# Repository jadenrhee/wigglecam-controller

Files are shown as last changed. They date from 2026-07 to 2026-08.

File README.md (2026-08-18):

# WiggleCam Camera Controller

The RP2040 board that handles timing-critical and analog work for a
[4-lens camera](https://github.com/jadenrhee/wigglecam). The Raspberry
Pi runs capture and image processing, but Linux is not a real-time OS
and the Pi can't drive the flash directly.

This board runs the LED flash at constant current, with the limits set
in the circuit rather than only in firmware. It also debounces the
shutter, decodes the EC11 encoder, and monitors battery voltage and
current through an INA219. On a trigger it pulses the Pi the instant the
LEDs reach full current.

The Pi drives it over I2C at 0x17, and the capture pulse returns on its
own GPIO line. The 2x6 header maps 1:1 onto Pi 5 GPIO pins 1 to 12.

Not fabricated yet, so everything here comes from the design files.

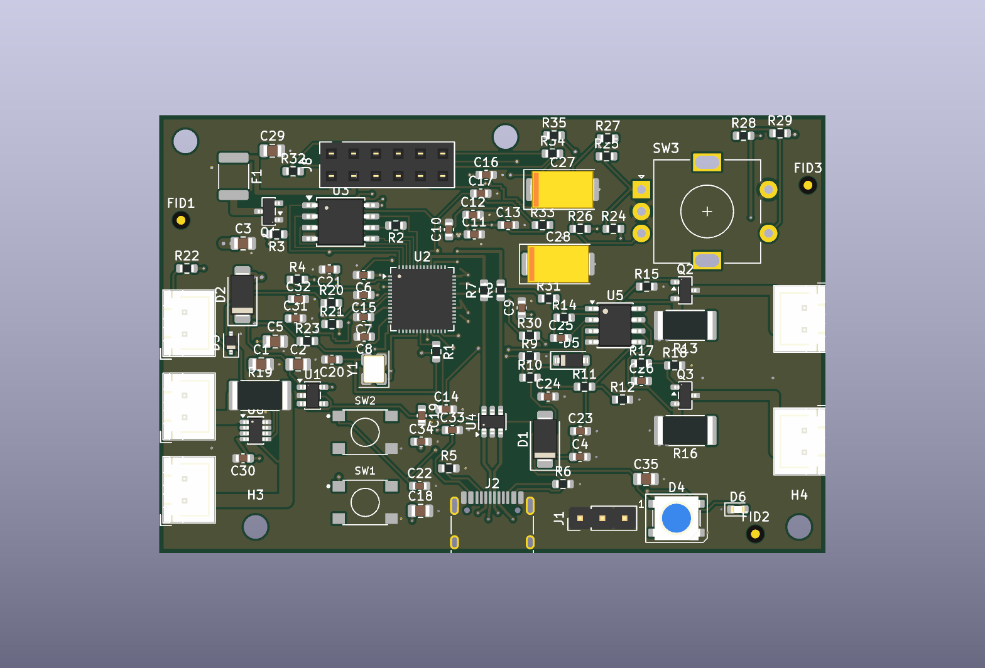
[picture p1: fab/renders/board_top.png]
Board, top

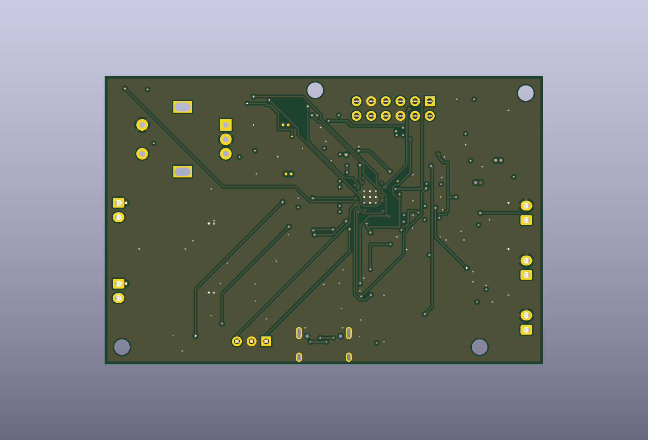
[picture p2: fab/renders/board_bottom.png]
Board, bottom


Signal routing, front copper red and back copper blue, planes hidden:

Routing view

| | |
|---|---|
| Board | 76 x 50 mm, 4 layers |
| Schematic | ERC clean, 0 errors and 0 warnings |
| Layout | DRC clean, 0 violations and 0 unconnected, against JLCPCB's published 4-layer rules |
| Verification | 24 checks measured off the finished layout, no failures. [Report](docs/verification-report.md) |
| Firmware | builds clean under the Pico SDK |
| Fab outputs | Gerbers, drill, BOM, and placement files in [fab/](fab/); the ready-to-upload set is [fab/jlc/](fab/jlc/) |

## Repo layout

| Path | Contents |
|---|---|
| [hardware/skidl/](hardware/skidl/) | schematic as code, the source of record |
| [hardware/kicad/](hardware/kicad/) | the board file and custom footprints |
| [hardware/partlist.md](hardware/partlist.md) | every part, the reasoning behind it, and where to order it |
| [fab/](fab/) | Gerbers, Excellon drill, `bom.csv`, `cpl.csv`, renders |
| [firmware/](firmware/) | C firmware: I2C register file, flash safety logic, INA219, EC11, WS2812 |
| [enclosure/](enclosure/) | 3D-printable pod holding the screen, this board, and the Pi 5 |
| [docs/](docs/) | [verification report](docs/verification-report.md), [design rationale](docs/design-rationale.md), and the [Pi protocol](docs/protocol.md) |

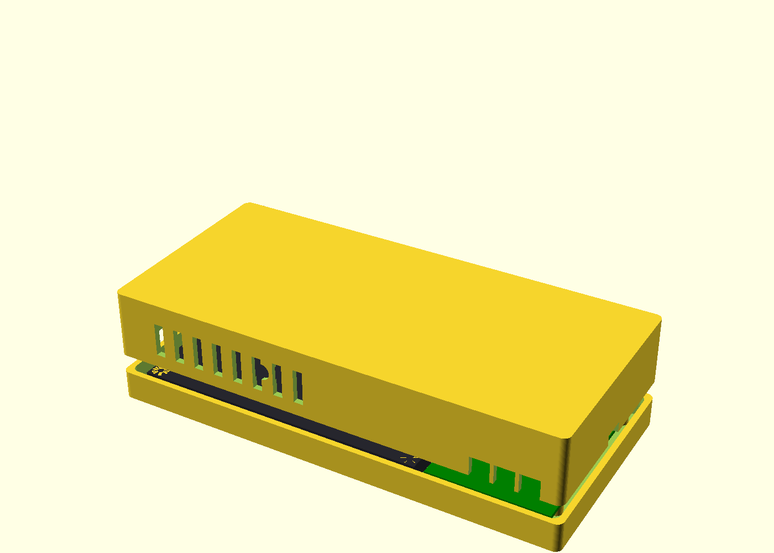
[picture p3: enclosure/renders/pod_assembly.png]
pod


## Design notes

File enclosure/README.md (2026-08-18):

# Control pod enclosure

Two-shell 3D-printable case (≈191 × 89 × 40 mm) housing the camera's
brain: the 4.3" DSI touchscreen behind the left of the face, this
repo's controller PCB behind the right-hand control strip (components
facing out so the encoder knob, status-LED light pipe and
BOOTSEL/RUN poke-holes come through the face; USB-C exits the right wall), and a
Raspberry Pi 5 flat on the rear floor.

assembly
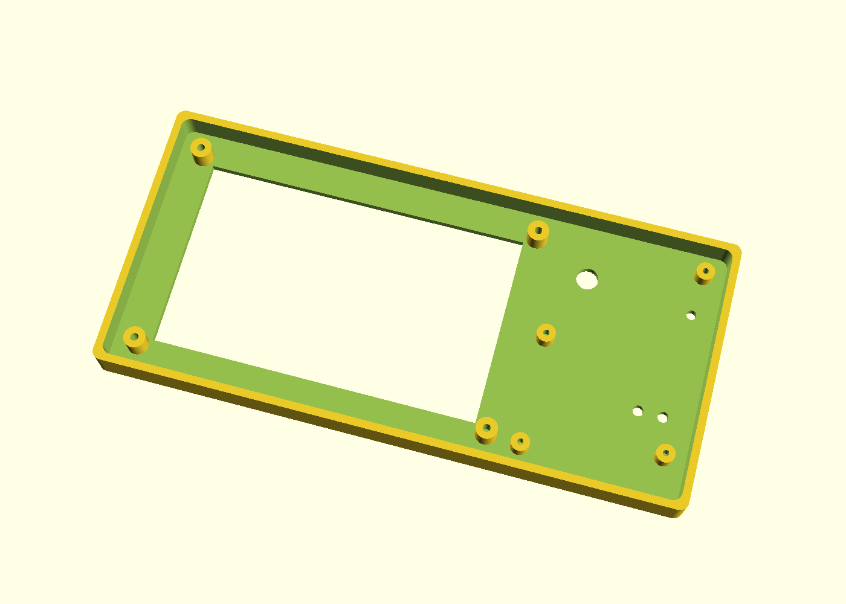
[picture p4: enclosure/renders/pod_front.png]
front shell

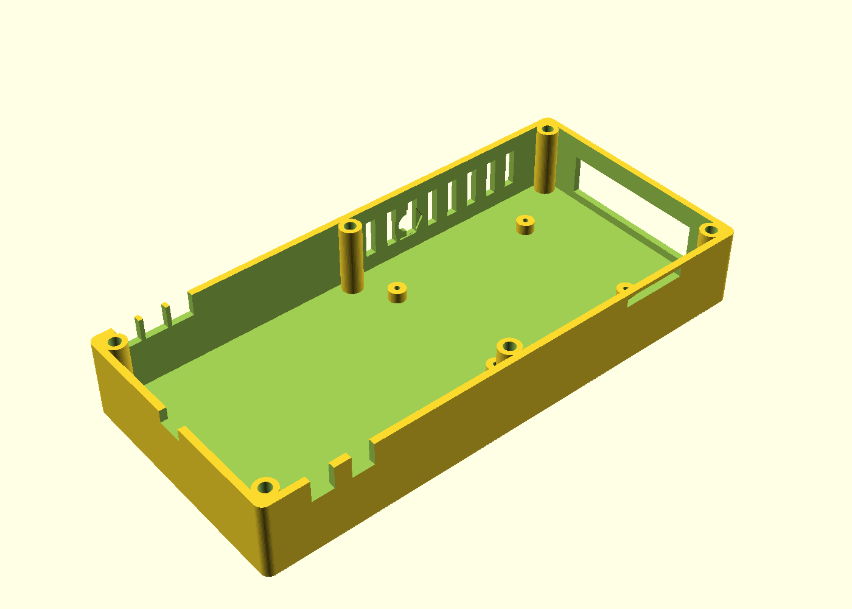
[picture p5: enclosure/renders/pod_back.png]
back shell


**The PCB cannot mis-mate:** every board-related feature (mounting
bosses, encoder hole, LED pipe, button holes, USB-C window, cable
slots) is generated from the routed `.kicad_pcb` via
the routed board → [board_dims.scad](board_dims.scad).
If the layout ever changes, re-run the extractor and re-export.

## Ordering prints (no printer needed)

Upload `stl/pod_front.stl` and `stl/pod_back.stl` to any of:

- **[JLC3DP](https://jlc3dp.com)** is the cheapest. Pick **SLS Nylon
  (PA12)** for a clean, strong result (~$15-25 for the pair), or resin
  if you want smoother faces.
- **[Craftcloud](https://craftcloud3d.com)** compares prices across
  many services.
- A **library / school makerspace** FDM printer also works: PETG,
  0.2 mm layers, 4 walls, 25 % infill; print both shells face-down
  (flat side on the bed), no supports needed except the side windows
  (bridging distance is small enough for a tuned printer).

**Before ordering**, measure your delivered screen with calipers and
update `scr_*` in [control_pod.scad](control_pod.scad), the
Waveshare 4.3" module outline/hole values here are typical but marked
`TODO(measure)` because vendor revisions drift.

## Assembly hardware

| Item | Qty | Use |
|---|-----|-----|
| M3 heat-set inserts + M3×12 screws | 6 | join the shells |
| M2×6 self-tapping screws | 4 | controller PCB onto its bosses |
| M2.5×6 self-tapping screws | 4 | Pi 5 onto the floor bosses |
| M3×6 self-tapping screws | 4 | screen module |
| 3 mm acrylic rod, ~6 mm piece | 1 | WS2812 light pipe (press-fit, dab of CA glue) |
| 12-way 2.54 mm ribbon, 2×6 IDC both ends, ~80 mm | 1 | controller J8 → Pi GPIO pins 1-12 |
| Knob for 6 mm D-shaft | 1 | encoder |
| The encoder's own M7 nut + washer | - | clamps the PCB assembly to the face |

## Assembly order

1. Heat-set the six M3 inserts into the back-shell towers.
2. Press the light pipe into the face from inside; trim flush.
3. Screw the controller PCB (components toward the face) onto its
   four bosses; add the encoder washer + nut on the outside; fit the
   knob.
4. Screw the screen into its pocket; route its DSI cable.
5. Screw the Pi onto the floor bosses (active cooler up); connect
   DSI to the screen, the 12-way ribbon to the controller, and the
   camera ribbon through the top slit.
6. Route the JST harnesses (LED ×2 top, VBAT ×2 + shutter bottom)
   through their slots before closing.
7. Close the shells, six M3 screws. The 1/4-20 nut epoxies into the
   bottom pocket for tripod use.

## Regenerating

```bash
# dimensions from the PCB (KiCad's bundled python):
KIPY private/scripts/08_enclosure_dims.py
# STLs + renders:
OpenSCAD -o enclosure/stl/pod_front.stl -D 'PART="front"' enclosure/control_pod.scad
OpenSCAD -o enclosure/stl/pod_back.stl  -D 'PART="back"'  enclosure/control_pod.scad
```

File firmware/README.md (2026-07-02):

# Camera Controller firmware

RP2040 firmware (Pico SDK, C). See [../docs/protocol.md](../docs/protocol.md)
for the I2C register map the Pi talks to.

## Build

```bash
export PICO_SDK_PATH=~/pico-sdk
# any arm-none-eabi toolchain with newlib; xpack works well:
export PICO_TOOLCHAIN_PATH=~/tools/xpack-arm-none-eabi-gcc-14.2.1-1.1/bin
cmake -B build -S . -DCMAKE_BUILD_TYPE=Release
make -C build -j4
```

Flash: hold BOOTSEL while plugging USB-C, then copy
`build/camctrl.uf2` to the RPI-RP2 drive.

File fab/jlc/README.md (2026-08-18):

# JLCPCB upload set

Three files, in this order.

| Step | File |
|---|---|
| PCB | `../wigglecam_gerbers.zip` (upload as-is, do not unzip) |
| BOM | `bom-smt.csv` |
| Placement | `cpl-smt.csv` |

PCB settings: **4 layers**, 76 x 50 mm, **1.6 mm** thickness, 1 oz outer
copper. Assembly: **top side only** (all 90 placements are top side).

## What these files are

`bom-smt.csv` / `cpl-smt.csv` hold the 90 surface-mount placements and
nothing else. The eight through-hole parts are split out into
`bom-handsolder.csv` so the upload has no rows JLC has to reject.

`../bom.csv` and `../cpl.csv` remain the complete set for the whole
board, all 98 placements.

## Hand-soldered separately

J1, J3, J4, J5, J6, J7, J8, SW3. Buy these yourself; they are not in
the JLC upload. All are 2.54 mm headers, JST-XH, or the EC11 encoder,
so none of them is difficult.

## Parts to confirm in the picker

Stock moves daily, so the last step happens in JLC's BOM tool, not
here. Note that JLC's assembly inventory is a different pool from
LCSC's retail stock: a part can be buyable at LCSC and still show a
shortfall in the BOM tool. When that happens the cheapest fix is
usually to deselect it and hand-solder one bought from LCSC.

Expect to resolve these:

- **R12** is C22765 (1.2 k 0603 1 %, JLC basic). It sets the flash
  reference: 1.2 k settles at 0.508 V, giving 1.015 A per LED branch.
  **Do not substitute 1 k** (0.434 V, 0.87 A) or 1.1 k (0.471 V,
  0.94 A).
- **D4 (WS2812B)** is often flagged "Standard Only" on Economic
  assembly. Deselect and hand-solder it if so; it is a 4-pad 5050.
- Anything showing an inventory shortfall: deselect it and hand-solder,
  or pick an equivalent. Nothing here is exotic except the parts
  called out in `../../hardware/partlist.md`.

The one part that cannot simply be dropped is **U1 (AP2112K-3.3,
SOT-23-5)**. It is the 3.3 V rail for the RP2040, flash, INA219 and
WS2812, so the board does nothing without it. If C51118 is short, use
**ME6211C33M5G-N (C82942)**: same SOT-23-5 pinout, 500 mA instead of
600 mA, which still leaves better than 2x margin on this board's
221 mA worst case. Any other substitute needs its pinout checked
against 1 VIN, 2 GND, 3 EN, 4 NC, 5 VOUT first, because plenty of
SOT-23-5 regulators number those differently.

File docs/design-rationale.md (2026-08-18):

# Design rationale, block by block

Datasheets:

- [RP2040](https://datasheets.raspberrypi.com/rp2040/rp2040-datasheet.pdf)
- [Hardware design with RP2040](https://datasheets.raspberrypi.com/rp2040/hardware-design-with-rp2040.pdf)
- [W25Q128JV](https://www.winbond.com/resource-files/w25q128jv%20revf%2003272018%20plus.pdf)
- [AP2112](https://www.diodes.com/assets/Datasheets/AP2112.pdf)
- [USBLC6-2](https://www.st.com/resource/en/datasheet/usblc6-2.pdf)
- [INA219](https://www.ti.com/lit/ds/symlink/ina219.pdf)
- [AO3400A](http://aosmd.com/pdfs/datasheet/AO3400A.pdf) /
  [AO3401A](http://aosmd.com/pdfs/datasheet/AO3401A.pdf)
- [LM358](https://www.ti.com/lit/ds/symlink/lm358.pdf)

## MCU core
Bare RP2040 with the support circuit taken directly from the official
guide's Minimal Design Example: 12 MHz ABM8-272-T3 (CL = 10 pF → two
15 pF C0G load caps, 1 kΩ series on XOUT limits drive), W25Q128JVSIQ
QSPI flash 9 mm away with a 27 Ω series option in SCLK, 100 nF at
every IOVDD/USB_VDD/ADC_AVDD, two 100 nF + 1 µF on the internal
1.1 V regulator, BOOTSEL (QSPI_SS to GND) and RUN buttons wired on
diagonal tact-switch pads so either internal pairing convention works.

## Power input
Pi 5 V enters through a 3 A PTC and an AO3401A P-FET oriented
drain-to-input (body diode conducts at first power, channel then
enhances; reversed input blocks). The post-FET node **is** the flash
rail (VLED) and feeds the logic rail through one of two SS34 OR-diodes.
The other diode comes from USB VBUS, so a bench USB port can never be
asked for the 2 A flash pulse. AP2112K-3.3 (600 mA) supplies logic
with 3× margin.

## Flash driver
Two independent op-amp constant-current sinks (½ LM358 + AO3400A +
0.5 Ω sense each): I = VREF / 0.5 Ω, VREF = 0-0.5 V from an RC-filtered
RP2040 PWM through a 5.6 k/1.2 k divider. The RC filter's 1 k sits in
series with the top leg, so the bottom leg is 1.2 k, not 1 k,
and full scale settles at 3.3 × 1.2/(1 + 5.6 + 1.2) ≈ 0.51 V
(1.015 A/branch). A 100 kΩ pulldown holds the reference at zero through reset, so the
flash cannot fire until firmware commands it. An AL8860 buck was
rejected because from a 5 V rail it cannot drive a series LED string
(Vf 6-9 V), which would mean one
driver+inductor per LED, all JLC extended parts. Worst-case sink
dissipation ≈1.4 W for ≤150 ms (firmware-capped, plus 800 ms
cooldown), within the SOT-23 single-pulse transient envelope with
margin (AO3400A Zth curve). Reservoir: 2× 470 µF low-ESR polymer on
the VLED island.

## Battery monitor
INA219 high-side on a JST-in/JST-out pass-through with a 10 mΩ 2 W
shunt (5 A → 50 mV, inside the ±320 mV PGA range). It lives on a
separate internal I2C bus (RP2040 master) so its traffic never
touches the Pi-facing bus; firmware caches readings. The layout's
sense taps are not Kelvin. They join the 1.5 mm battery trace a few
mm from the shunt pads, so roughly 3 mΩ of trace copper sits inside
the sense loop and uncorrected readings run ~30 % high. Firmware
carries an effective-shunt-resistance trim constant
(`SHUNT_EFF_MOHM`, firmware/src/ina219.c) to calibrate out at
bring-up.

## Controls & status
Shutter and encoder lines get 10 k pullups + 1 k series + 100 nF RC
(hardware debounce first stage). The shutter leaves the enclosure, so
it also gets a PESD5V0S1BA TVS at the connector. WS2812B runs its
VDD through a 1N4148W drop (~4.3 V) so 3.3 V logic meets the 0.7·VDD
input threshold. One green LED on GPIO25 keeps the Pico debugging
convention.

## Pi interface
2×6 socket matching Pi 5 GPIO pins 1-12 exactly: I2C (slave 0x17),
a UART pair (wired, unused by the current firmware), camera-sync out
(→ Pi GPIO17), event/ATTN line (→ Pi GPIO18),
5 V in, grounds. 330 Ω series resistors on the push-pull lines as
contention insurance; the I2C lines connect directly because the Pi 5
carries 1.8 kΩ hardware pullups.

## Board & layout strategy
76×50 mm 4-layer (JLC04161H-7628): L1 signal, L2 solid GND, L3 3V3
plane + a tightly-drawn VLED island (west entry lobe → 1.6 mm conduit
finger → reservoir pocket → right strip to the LED connectors), L4
signal. The sensitive geometry (QSPI nested-lane fanout, crystal, USB
pair with its mirror-pad B.Cu jumpers, power entry, battery path, LED
returns, plane fanouts) is laid out with explicit crossing-free
geometry, and the inner layers carry no signal routing at all, so the
planes stay whole under the fast nets. Everything gates through
`kicad-cli drc --refill-zones` at JLCPCB capability limits. The
final board reports **0 violations, 0 unconnected** (see
docs/verification-report.md).

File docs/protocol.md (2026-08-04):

# Pi ⇄ Camera Controller protocol

Bus: I2C, RP2040 as slave at **0x17** on the Pi's I2C1 (GPIO2/3,
400 kHz; the Pi 5's onboard 1.8 kΩ pullups serve the bus). Register
semantics follow SMBus conventions: write `[reg]` then data bytes
(auto-increment), or write `[reg]` + repeated-start read.

A second signal, **ATTN** (RP2040 GPIO7 → Pi GPIO18), goes high while
any button/encoder event is latched, so the Pi can poll cheaply or
take a GPIO interrupt instead of polling I2C.

The capture-sync line (**RP2040 GPIO6 → Pi GPIO17**) pulses high when
a trigger fires; the Pi's capture loop waits on this edge so the
exposure lands inside the flash window.

## Register map

| Addr | Name | R/W | Meaning |
|---|---|-----|---|
| 0x00 | WHO_AM_I | R | always 0xCA |
| 0x01 | STATUS | R | bit0 trigger engine busy (flash or sync pulse in progress), bit1 event pending |
| 0x02 | TRIGGER | W | 1 = sync pulse only; 2 = flash + sync (flash reaches steady current ~5 ms before the sync edge; degrades to sync only if FLASH_PCT is 0 **or during the 800 ms post-flash cooldown**, but the sync edge always arrives); any other value is ignored. Writes while STATUS bit0 is set are dropped, so poll it before triggering. Back-to-back writes coalesce (last one wins). |
| 0x03 | FLASH_MS | RW | flash duration, clamped 1-150 ms (default 30) |
| 0x04 | FLASH_PCT | RW | flash current 0-100 % of 1.00 A/branch (default 80) |
| 0x05 | FIRE_FLASH | W | flash pulse without sync (e.g. focus assist) |
| 0x06-07 | VBAT | R | battery voltage, mV, little-endian u16; read low byte first, which snapshots the high byte so the pair is tear-free. A high byte read without its low byte returns the previous snapshot, not the live value |
| 0x08-09 | IBAT | R | battery current, mA, little-endian i16; same low-byte-first snapshot rule |
| 0x0A | ENC_DELTA | R | signed whole-detent count since last read (clears; a sub-detent remainder carries into the next read) |
| 0x0B | BUTTONS | R | bit0 shutter, bit1 encoder push (clears; ATTN drops once no events remain) |
| 0x0C-0E | LED R/G/B | RW | status LED color staging |
| 0x0F | LED_APPLY | W | latch staged RGB to the WS2812B |

Writes to read-only registers are dropped.

## Safety behavior (firmware-enforced, mirrors the hardware)

- Total LED-on time hard-capped at 150 ms; the ~5 ms pre-sync settle
  counts against the cap. 800 ms cooldown between pulses (SOT-23 sink
  transient thermal budget).
- The PWM pin idles low and the board's 100 kΩ pulldown holds the
  current-sink reference at 0 V through reset/boot, so the flash
  cannot fire until firmware explicitly commands it.
- 500 ms hardware watchdog; a hung firmware resets to flash-off.

## Example (Pi side, python3-smbus2)

```python
from smbus2 import SMBus
bus = SMBus(1)
assert bus.read_byte_data(0x17, 0x00) == 0xCA
bus.write_byte_data(0x17, 0x03, 40)   # 40 ms flash
bus.write_byte_data(0x17, 0x04, 90)   # 90 % current
bus.write_byte_data(0x17, 0x02, 2)    # flash + sync capture
mv = bus.read_word_data(0x17, 0x06)   # battery mV
```

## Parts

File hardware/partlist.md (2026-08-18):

# Part list (verified against LCSC stock, 2026-07-02)

Every named part below was individually confirmed present and in stock
at LCSC on the date above, except where a row says "confirm at order". Prices are the LCSC
from-price at qty 1; re-check stock at order time, it moves.
"JLC class" (basic vs extended, affects assembly setup fees) should be
confirmed in the JLCPCB BOM tool at order time; known classes noted.

**2026-07-03 update:** refdes corrected to match the routed board
(`fab/bom.csv` is the authoritative refdes source), generic-passive
picks added (each number verified against its LCSC product page for
value + package), and the 470 µF reservoir got its concrete pick.

## MCU core

| Ref | Part | Package | LCSC | ~$ | Notes |
|-----|---|---|---|----|---|
| U2 | [RP2040](https://www.lcsc.com/product-detail/C2040.html) | QFN-56 7×7 | **C2040** | 0.70 | in stock; support circuit per the official *Hardware design with RP2040* guide |
| U3 | [W25Q128JVSIQ](https://www.lcsc.com/product-detail/NOR-FLASH_Winbond-Elec-W25Q128JVSIQ_C97521.html) 16 MB QSPI | SOIC-8 | **C97521** | 0.47 | in stock; the flash used on the Pico |
| Y1 | [ABM8-272-T3](https://www.lcsc.com/product-detail/C20625731.html) 12 MHz, CL = 10 pF | 3225 | **C20625731** | 0.15 | in stock; the exact crystal from the RP2040 guide's minimal example → 15 pF load caps + 1 kΩ series R on XOUT, straight from the guide |
| SW1, SW2 | [TS-1187A-B-A-B](https://www.lcsc.com/product-detail/C318884.html) BOOTSEL + RUN | SMD 5.1 mm | **C318884** | 0.01 | in stock, JLC **basic**. Known deviation: no 1 kΩ in series with the BOOTSEL button (reference design has one) |
| J1 | SWD header 1×3, 2.54 mm | THT | generic | - | hand-solder; any vendor |

## Power

| Ref | Part | Package | LCSC | ~$ | Notes |
|-----|---|---|---|----|---|
| U1 | [AP2112K-3.3TRG1](https://www.lcsc.com/product-detail/C51118.html) 600 mA LDO | SOT-23-5 | **C51118** | 0.09 | **Alternate if short: [ME6211C33M5G-N](https://www.lcsc.com/product-detail/C82942.html) (C82942), 278 k in stock.** Same SOT-23-5 pinout (1 VIN, 2 GND/VSS, 3 EN/CE, 4 NC, 5 VOUT), 500 mA instead of 600 mA. The 3V3 rail draws 221 mA worst case (RP2040 200 mA peak + INA219 + WS2812), so 44 % of rating, and dropout at 200 mA is 260 mV against ~1.0 V of headroom from VSYS. Same 1 µF/10 µF caps. |
| Q1 | [AO3401A](https://www.lcsc.com/product-detail/C15127.html) P-ch, reverse-polarity protection | SOT-23 | **C15127** | 0.05 | in stock, JLC **basic**; polarity-critical in the JLC preview |
| D1, D2 | [SS34](https://www.lcsc.com/product-detail/C8678.html) 3 A Schottky, VBUS/VLED diode-OR | SMA | **C8678** | 0.03 | cathode bands polarity-critical in the JLC preview |
| F1 | [BSMD1812-300-16V](https://www.lcsc.com/product-detail/C883162.html) PTC, 3 A hold | 1812 | **C883162** | - | Pi-5V input fuse |

## USB-C

| Ref | Part | Package | LCSC | ~$ | Notes |
|-----|---|---|---|----|---|
| J2 | [TYPE-C-31-M-12](https://www.lcsc.com/product-detail/USB-Type-C_Korean-Hroparts-Elec-TYPE-C-31-M-12_C165948.html) 16-pin | SMD+THT shell | **C165948** | 0.10 | in stock; the de-facto hobby USB-C jack, hand-solderable |
| U4 | [USBLC6-2SC6](https://www.lcsc.com/product-detail/C7519.html) ESD array | SOT-23-6 | **C7519** | 0.08 | in stock; in D± path before the MCU |
| R7, R8 | 27 Ω 1 % D± series | 0603 | **C25190** | - | guide-nominal 27 Ω (Pico's 27.4 Ω is the E96 neighbour, equivalent at USB-FS); JLC **basic** |

## Flash driver (constant-current, discrete; see decision note below)

| Ref | Part | Package | LCSC | ~$ | Notes |
|-----|---|---|---|----|---|
| U5 | [LM358DR2G](https://www.lcsc.com/product-detail/General-Purpose-Amplifiers_ON-Semiconductor-LM358DR2G_C7950.html) dual op-amp | SOIC-8 | **C7950** | 0.03 | in stock, JLC **basic**; one half per LED branch |
| Q2, Q3 | [AO3400A](https://www.lcsc.com/product-detail/MOSFET_AOS_AO3400A_AO3400A_C20917.html) N-ch sink FETs | SOT-23 | **C20917** | 0.05 | in stock, JLC **basic**; 150 ms pulse-thermal disposition in the verification report |
| R13, R16 | [RTT25R500FTE](https://www.lcsc.com/product-detail/C105149.html) 0.5 Ω 1 % 1 W sense | 2512 | **C105149** | 0.02 | 1 A per branch → 0.5 V sense; 0.5 W only during the ≤150 ms pulse |
| C27, C28 | [6TPE470MI](https://www.lcsc.com/product-detail/Tantalum-Capacitors_PANASONIC_C402828.html) 470 µF 6.3 V 18 mΩ POSCAP | EIA-7343 | **C402828** | - | the low-ESR polymer reservoir the sizing math assumes; 6.3 V on a ~4.9 V rail ≈ 78 %, inside polymer derating practice |
| J3, J4 | [B2B-XH-A(LF)(SN)](https://www.lcsc.com/product-detail/C158012.html) JST-XH 2-pin, LED branches out | THT | **C158012** | - | genuine JST; LEDs (2× XP-G3 stars) live off-board at the flash window; hand-solder |

**Why a discrete sink instead of the AL8860:** the AL8860 is a *buck*
driver, so from a 5 V rail it cannot drive a 2-3-LED series string
(6-9 V); you'd need one AL8860 + inductor per LED, all JLC extended
parts. The discrete sink (LM358 + AO3400A + sense R, all JLC basic)
drives two parallel 1 A branches from 5 V at lower cost, with true
constant-current regulation. Reference for the sinks comes from an
RP2040 PWM pin through an RC filter (adjustable flash power); a
100 kΩ pulldown on that node holds the reference at 0 V during boot,
so the flash physically cannot fire until firmware drives it.

## Battery monitor

| Ref | Part | Package | LCSC | ~$ | Notes |
|-----|---|---|---|----|---|
| U6 | [INA219AIDCNR](https://www.lcsc.com/product-detail/C87469.html) | SOT-23-8 | **C87469** | 0.33 | in stock; on an internal I2C bus (RP2040 master), separate from the Pi-facing bus |
| R19 | [GX2512-2W-10mR-1%](https://jlcpcb.com/partdetail/Milliohm-GX2512_2W_10mR_1/C500718) shunt | 2512 2 W | **C500718** | - | in stock; 5 A → 50 mV drop, 0.25 W, inside the INA219 ±320 mV range |
| J5, J6 | [B2B-XH-A(LF)(SN)](https://www.lcsc.com/product-detail/C158012.html) JST-XH battery pass-through (in/out) | THT | **C158012** | - | battery lead routes through the shunt; can be left unpopulated and the leads soldered straight into the through-holes; hand-solder |

## Controls & status

| Ref | Part | Package | LCSC | ~$ | Notes |
|-----|---|---|---|----|---|
| J7, D3 | Shutter via [B2B-XH-A](https://www.lcsc.com/product-detail/C158012.html) JST-XH (panel button off-board) + RC debounce + [PESD5V0S1BA,115](https://www.lcsc.com/product-detail/C19224.html) TVS | THT / SOD-323 | **C158012** / **C19224** | - | TVS in stock (328 k units), Nexperia original |
| SW3 | [EC11E18244AU](https://www.lcsc.com/product-detail/C202365.html) rotary encoder w/ push | THT | **C202365** | - | in stock, genuine ALPS; shaft length vs enclosure = TODO(measure); hand-solder |
| D4 | [WS2812B-B/T](https://www.lcsc.com/product-detail/Light-Emitting-Diodes-LED_Worldsemi-WS2812B-B-T_C2761795.html) status RGB | 5050 | **C2761795** | 0.05 | in stock at LCSC; reports exist of JLC assembly rejecting the 5050 variant; hand-solder fallback (easy). VDD fed through a 1N4148 drop (~4.3 V) so 3.3 V data meets the 0.7·VDD input threshold |
| D5 | [1N4148W](https://www.lcsc.com/product-detail/C81598.html) WS2812 VDD drop | SOD-123 | **C81598** | - | |
| D6 | [Green LED](https://www.lcsc.com/product-detail/C72043.html) debug, GPIO25 | 0603 | **C72043** | - | |
| J8 | 2×6 female socket, 2.54 mm, Pi interface | THT | generic | - | maps 1:1 onto Pi 5 GPIO pins 1-12, see below; hand-solder; any vendor |

## Generic passives (JLC picks, value + package verified 2026-07-03)

All 0603/0805 lines are JLC-basic-class commodity parts; refdes
groupings match `fab/bom.csv`.

| Value | Refs | Package | LCSC | Part |
|---|---|---|---|---|
| 100 nF X7R 50 V | C6-C15, C21-C23, C30-C34 (×18) | 0603 | **C14663** | YAGEO CC0603KRX7R9BB104 |
| 1 µF X5R | C4, C16, C17, C24 | 0603 | **C15849** | Samsung CL10A105KB8NNNC |
| 15 pF C0G 50 V (crystal load) | C19, C20 | 0603 | **C1644** | Samsung CL10C150JB8NNNC |
| 1 nF X7R (comp) | C25, C26 | 0603 | **C1588** | Samsung CL10B102KB8NNNC |
| 10 µF X5R 25 V | C3, C5, C18, C29, C35 | 0805 | **C15850** | Samsung CL21A106KAYNNNE |
| 22 µF X5R 25 V (VSYS bulk) | C1, C2 | 0805 | **C45783** | Samsung CL21A226MAQNNNE |
| 27 Ω 1 % | R2, R7, R8 | 0603 | **C25190** | UNI-ROYAL |
| 100 Ω 1 % | R14, R17 | 0603 | **C22775** | UNI-ROYAL 0603WAF1000T5E |
| 330 Ω 1 % | R32-R35 | 0603 | **C23138** | UNI-ROYAL 0603WAF3300T5E |
| 470 Ω 1 % | R30 | 0603 | **C23179** | UNI-ROYAL 0603WAF4700T5E |
| 1 kΩ 1 % | R1, R10, R23, R25, R27, R29, R31 | 0603 | **C21190** | UNI-ROYAL 0603WAF1001T5E |
| 1.2 kΩ 1 % | R12 | 0603 | **C22765** | UNI-ROYAL 0603WAF1201T5E, JLC **basic**. VREF divider bottom leg, sized against the RC filter's 1 kΩ source impedance: full scale settles at 0.508 V → 1.015 A/branch. A plain 1 k gives 0.434 V → 0.87 A, which is why this leg is not 1 k. E96 1.18 k is the exact fit (0.5005 V) but is thinly stocked; 1.2 k is the common-value substitute and the 1.5 % is immaterial |
| 4.7 kΩ 1 % | R20, R21 | 0603 | **C23162** | UNI-ROYAL 0603WAF4701T5E |
| 5.1 kΩ 1 % | R5, R6 | 0603 | **C23186** | UNI-ROYAL 0603WAF5101T5E |
| 5.6 kΩ 1 % | R11 | 0603 | **C23189** | UNI-ROYAL 0603WAF5601T5E |
| 10 kΩ 1 % | R3, R4, R22, R24, R26, R28 | 0603 | **C25804** | UNI-ROYAL 0603WAF1002T5E |
| 100 kΩ 1 % | R9, R15, R18 | 0603 | **C25803** | UNI-ROYAL 0603WAF1003T5E |

## Pi interface header (2×6, matches Pi 5 pins 1-12 exactly)

| Pi pin | Signal | Board use |
|---|---|---|
| 1 | 3V3 | reference only (not a power source) |
| 2, 4 | 5V | board power in (through Q1 reverse protection) |
| 3 / 5 | GPIO2 SDA / GPIO3 SCL | I2C, RP2040 slave @ 0x17. Pi has 1.8 kΩ hardware pullups on these pins, so the board adds none (optional solder-jumper 4.7 k for standalone bench use) |
| 6, 9 | GND | |
| 7 | GPIO4 | spare |
| 8 / 10 | GPIO14 TXD / GPIO15 RXD | UART pair, wired to RP2040 GPIO0/1 (unused; the firmware speaks I2C only) |
| 11 | GPIO17 | **camera-sync trigger** (RP2040 → Pi input) |
| 12 | GPIO18 | **ATTN** event flag (RP2040 GPIO7 → Pi input, see docs/protocol.md) |

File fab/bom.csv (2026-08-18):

Comment | Designator | Footprint | LCSC
22uF | C1,C2 | C_0805_2012Metric | C45783
15pF | C19,C20 | C_0603_1608Metric | C1644
1nF | C25,C26 | C_0603_1608Metric | C1588
470uF | C27,C28 | CP_EIA-7343-30_AVX-N | C402828
10uF | C18,C29,C3,C35,C5 | C_0805_2012Metric | C15850
1uF | C16,C17,C24,C4 | C_0603_1608Metric | C15849
100nF | C10,C11,C12,C13,C14,C15,C21,C22,C23,C30,C31,C32,C33,C34,C6,C7,C8,C9 | C_0603_1608Metric | C14663
SS34 | D1,D2 | D_SMA | C8678
PESD5V0S1BA | D3 | D_SOD-323 | C19224
WS2812B | D4 | LED_WS2812B_PLCC4_5.0x5.0mm_P3.2mm | C2761795
1N4148W | D5 | D_SOD-123 | C81598
GREEN | D6 | LED_0603_1608Metric | C72043
PTC 3A | F1 | Fuse_1812_4532Metric | C883162
SWD | J1 | PinHeader_1x03_P2.54mm_Vertical
USB-C | J2 | USB_C_Receptacle_HRO_TYPE-C-31-M-12 | C165948
LED1 | J3 | JST_XH_B2B-XH-A_1x02_P2.50mm_Vertical | C158012
LED2 | J4 | JST_XH_B2B-XH-A_1x02_P2.50mm_Vertical | C158012
VBAT_IN | J5 | JST_XH_B2B-XH-A_1x02_P2.50mm_Vertical | C158012
VBAT_OUT | J6 | JST_XH_B2B-XH-A_1x02_P2.50mm_Vertical | C158012
SHUTTER | J7 | JST_XH_B2B-XH-A_1x02_P2.50mm_Vertical | C158012
Pi GPIO 1-12 | J8 | PinSocket_2x06_P2.54mm_Vertical
AO3401A | Q1 | SOT-23 | C15127
AO3400A | Q2,Q3 | SOT-23 | C20917
1k | R1,R10,R23,R25,R27,R29,R31 | R_0603_1608Metric | C21190
5.6k | R11 | R_0603_1608Metric | C23189
1.2k | R12 | R_0603_1608Metric | C22765
0.5R 1% | R13,R16 | R_2512_6332Metric | C105149
100R | R14,R17 | R_0603_1608Metric | C22775
10mR 2W 1% | R19 | R_2512_6332Metric | C500718
27R | R2,R7,R8 | R_0603_1608Metric | C25190
4.7k | R20,R21 | R_0603_1608Metric | C23162
10k | R22,R24,R26,R28,R3,R4 | R_0603_1608Metric | C25804
470R | R30 | R_0603_1608Metric | C23179
330R | R32,R33,R34,R35 | R_0603_1608Metric | C23138
5.1k | R5,R6 | R_0603_1608Metric | C23186
100k | R15,R18,R9 | R_0603_1608Metric | C25803
TACT | SW1,SW2 | SW_TS-1187A_5.1x5.1mm | C318884
EC11 | SW3 | RotaryEncoder_Alps_EC11E-Switch_Vertical_H20mm | C202365
AP2112K-3.3 | U1 | SOT-23-5 | C51118
RP2040 | U2 | QFN-56-1EP_7x7mm_P0.4mm_EP3.2x3.2mm | C2040
W25Q128JVSIQ | U3 | SOIC-8_5.3x5.3mm_P1.27mm | C97521
USBLC6-2SC6 | U4 | SOT-23-6 | C7519
LM358 | U5 | SOIC-8_3.9x4.9mm_P1.27mm | C7950
INA219 | U6 | SOT-23-8 | C87469
12MHz | Y1 | Crystal_SMD_3225-4Pin_3.2x2.5mm | C20625731

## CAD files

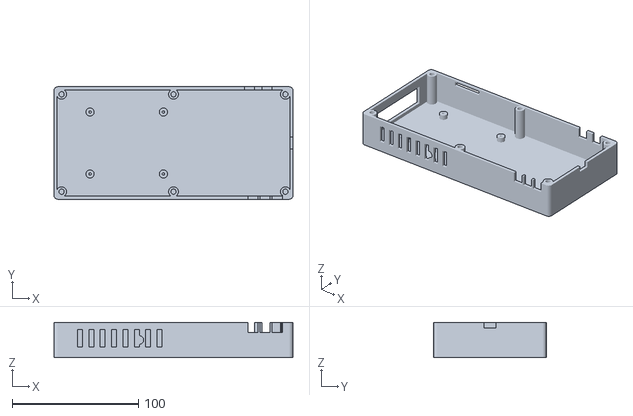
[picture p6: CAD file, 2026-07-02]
enclosure/stl/pod_back.stl
189.0 x 89.0 x 28.0

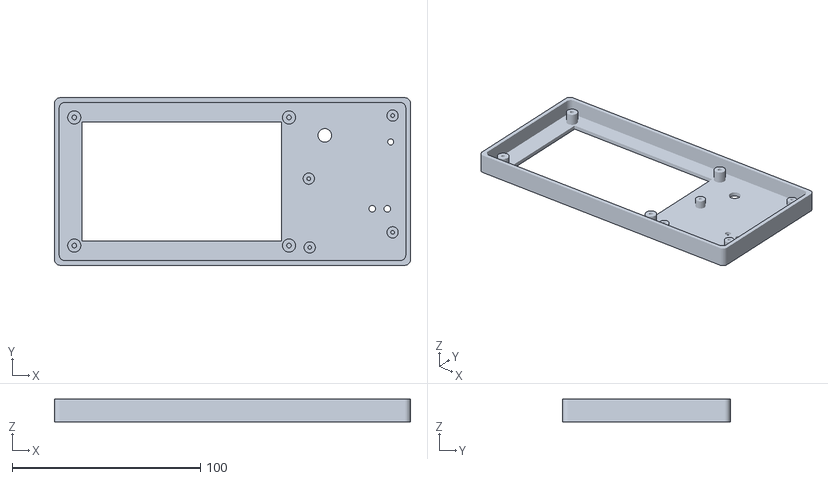
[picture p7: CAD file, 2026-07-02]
enclosure/stl/pod_front.stl
189.0 x 89.0 x 12.0

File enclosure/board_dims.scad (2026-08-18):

// GENERATED from
// hardware/kicad/wigglecam.kicad_pcb — do not edit by hand.
// Board-local mm, origin top-left, y DOWN (KiCad convention).

pcb_w = 76.0;
pcb_h = 50.0;
pcb_t = 1.6;

// M2.5 mounting holes
pcb_holes = [[3.00, 3.00], [39.50, 2.50], [11.00, 47.00], [73.00, 47.00]];

// EC11 encoder: 7 mm threaded bushing on the shaft axis,
// body height above PCB ~6.5 mm, shaft H20 variant
enc_shaft = [62.50, 11.00];
enc_bush_d = 7.2;   // clearance for the M7 bushing
enc_body_h = 6.5;

// USB-C receptacle, mouth out the bottom (y = pcb_h) edge
usbc_center = [38.00, 47.70];
usbc_w = 9.6;  usbc_h = 3.6;   // cutout incl. clearance

// WS2812B status LED (5x5) — light pipe location
ws2812 = [59.00, 46.00];

// BOOTSEL / RUN tact switches (actuator ~1.5 mm above body)
btn_bootsel = [23.50, 44.20];
btn_run = [23.50, 36.20];

// SWD header (internal, no cutout needed)
swd = [48.00, 46.00];

// JST-XH connectors (cable exits)
jst_led1 = [73.60, 22.00];
jst_led2 = [73.60, 36.00];
jst_vbat_in = [2.90, 34.50];
jst_vbat_out = [2.90, 44.00];
jst_shutter = [2.90, 25.00];

// Pi-interface 2x6 header (ribbon inside the enclosure)
pi_header = [19.65, 4.40];

// tallest component: JST-XH housings ~7.0 mm; keep >=4 mm
// clearance above them
pcb_max_comp_h = 7.0;
pcb_leg_h = 2.0;   // THT legs below the PCB

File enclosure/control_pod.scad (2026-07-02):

// ============================================================================
// WiggleCam control pod — two-shell enclosure for the camera's brain:
//   * Waveshare 4.3" DSI touchscreen (left of the user face)
//   * camera-controller PCB (this repo) behind the right-hand control
//     strip, components facing OUT: encoder knob, status-LED light
//     pipe and BOOTSEL/RUN poke-holes come through the face, USB-C
//     exits the right wall
//   * Raspberry Pi 5 flat on the rear-shell floor behind the screen
//
// All PCB feature positions come from board_dims.scad, which is
// GENERATED from the routed .kicad_pcb — the case cannot drift from
// the board. Screen and Pi dimensions are parameters: MEASURE YOUR
// DELIVERED PARTS with calipers before printing (vendor drawings
// drift between revisions).
//
// Set PART, render (F6), File > Export STL. Or headless:
//   OpenSCAD -o front.stl -D 'PART="front"' control_pod.scad
// ============================================================================

include <board_dims.scad>

PART = "assembly";   // "front" | "back" | "assembly"

// ---- outer geometry --------------------------------------------------------
wall   = 2.5;        // print-service safe for PETG / MJF nylon
gap    = 4;          // module-to-module breathing room
inner_h = 84;        // interior height (screen module 76 + margin)

// ---- screen (Waveshare 4.3" DSI — MEASURE YOURS, Rev 2.2+) ----------------
scr_w = 122;  scr_h = 76;      // module outline           TODO(measure)
scr_view_w = 106; scr_view_h = 63;  // visible area         TODO(measure)
scr_hole_dx = 114; scr_hole_dy = 68; // M3 pattern          TODO(measure)
scr_t = 8;                     // module thickness incl. PCB bulge

// ---- Raspberry Pi 5 --------------------------------------------------------
pi_w = 85;  pi_h = 56;
pi_hole_dx = 58; pi_hole_dy = 49; pi_hole_off = 3.5;  // from corner
pi_stack_h = 24;               // Pi + active cooler + margin

// ---- derived layout --------------------------------------------------------
// user face: [gap][screen 122][gap][controller strip pcb_h=50][gap]
strip_w  = pcb_h;                       // controller mounts portrait
inner_w  = gap + scr_w + gap + strip_w + gap;
outer_w  = inner_w + 2*wall;
outer_h  = inner_h + 2*wall;
front_d  = 12;                          // front shell depth
back_d   = 28;                          // rear shell depth
scr_x0   = wall + gap;                  // screen pocket left edge
strip_x0 = wall + gap + scr_w + gap;    // strip left edge
face_cy  = outer_h/2;

// controller placement on the strip: board rotated -90° (as seen from
// the front), so board-local (x, y_down) -> face (u, v_up):
//   u = strip_x0 + y      v = wall + (inner_h-pcb_w)/2 + x
// (USB-C bottom edge -> right wall; encoder lands low-right)
strip_y0 = wall + (inner_h - pcb_w)/2;
function fpos(p) = [strip_x0 + p[1], strip_y0 + p[0]];

// screws joining the shells: M3 heat-set inserts in the back shell
screws = [[6, 6], [outer_w/2, 6], [outer_w-6, 6],
          [6, outer_h-6], [outer_w/2, outer_h-6], [outer_w-6, outer_h-6]];
insert_d = 4.2; insert_h = 6;

$fn = 48;

// ============================================================================
// helpers
// ============================================================================
module rbox(w, h, d, r=3) {
    linear_extrude(d) offset(r) offset(-r) square([w, h]);
}

module shell(depth) {                    // open box, floor at z=0
    difference() {
        rbox(outer_w, outer_h, depth);
        translate([wall, wall, wall])
            rbox(inner_w, inner_h, depth);
    }
}

module boss(h, screw_d=2.0, od=6) {      // standoff with pilot hole
    difference() {
        cylinder(d=od, h=h);
        translate([0, 0, 1]) cylinder(d=screw_d, h=h);
    }
}

// ============================================================================
// FRONT shell: bezel + screen pocket + control strip + PCB bosses
// ============================================================================
module front_shell() {
    difference() {
        shell(front_d);

        // screen viewing aperture (through the face)
        translate([scr_x0 + (scr_w-scr_view_w)/2,
                   face_cy - scr_view_h/2, -1])
            cube([scr_view_w, scr_view_h, wall+2]);

        // screen module pocket (recessed from the inside)
        translate([scr_x0 - 0.5, face_cy - scr_h/2 - 0.5, wall])
            cube([scr_w + 1, scr_h + 1, scr_t]);

        // ---- control strip cutouts, from the real PCB coordinates --
        // encoder bushing (fix with its own nut + washer)
        translate([fpos(enc_shaft)[0], fpos(enc_shaft)[1], -1])
            cylinder(d=enc_bush_d, h=front_d+2);
        // WS2812 light pipe (3 mm acrylic rod, press fit)
        translate([fpos(ws2812)[0], fpos(ws2812)[1], -1])
            cylinder(d=3.2, h=wall+2);
        // BOOTSEL / RUN poke-holes (pen tip; labels in silk below)
        for (p = [btn_bootsel, btn_run])
            translate([fpos(p)[0], fpos(p)[1], -1])
                cylinder(d=3.5, h=wall+2);
    }

    // screen corner bosses (M3 self-tap into plastic)
    for (sx = [-1, 1], sy = [-1, 1])
        translate([scr_x0 + scr_w/2 + sx*scr_hole_dx/2,
                   face_cy + sy*scr_hole_dy/2, wall])
            boss(scr_t - 1, screw_d=2.5, od=7);

    // controller PCB bosses — EXACT hole positions from the layout,
    // board component-side toward the face, 5 mm standoff so the
    // encoder body (6.5 mm) plus face wall consume the bushing height
    for (p = pcb_holes)
        translate([fpos(p)[0], fpos(p)[1], wall])
            boss(5, screw_d=2.0, od=6);
}

// ============================================================================
// BACK shell: Pi bay, vents, cable slots, USB window, tripod nut
// ============================================================================
module back_shell() {
    difference() {
        union() {
            shell(back_d);
            // heat-set insert towers for the shell screws
            for (p = screws)
                translate([p[0], p[1], wall])
                    difference() {
                        cylinder(d=insert_d+3.6, h=back_d-wall);
                        translate([0, 0, back_d-wall-insert_h])
                            cylinder(d=insert_d, h=insert_h+1);
                    }
        }

        // ---- right wall: controller USB-C (board bottom edge faces
        // this wall after the -90° mounting rotation).
        // v-position mirrors fpos(); depth = front_d + boss + pcb over
        // the parting line, i.e. near the parting face of this shell
        translate([outer_w - wall - 1,
                   strip_y0 + usbc_center[0] - usbc_w/2,
                   back_d - 4.5])
            cube([wall + 2, usbc_w, usbc_h + 1.4]);

        // ---- left wall: Pi ports window (USB-C power + micro-HDMI,
        // bench use; in the camera, power arrives via the harness)
        translate([-1, face_cy - 27, wall + 3])
            cube([wall + 2, 54, 15]);

        // ---- top wall: LED JST cable slots + camera-ribbon slit
        for (p = [jst_led1, jst_led2])
            translate([strip_x0 + p[1] - 4, outer_h - wall - 1,
                       back_d - 8])
                cube([8, wall + 2, 9]);
        translate([scr_x0 + 20, outer_h - wall - 1, back_d - 5])
            cube([24, wall + 2, 3.5]);   // 22-pin camera ribbon

        // ---- bottom wall: VBAT + shutter JST slots
        for (p = [jst_vbat_in, jst_vbat_out, jst_shutter])
            translate([strip_x0 + p[1] - 4, -1, back_d - 8])
                cube([8, wall + 2, 9]);

        // ---- vents over the Pi bay
        for (i = [0:7])
            translate([scr_x0 + 12 + i*9, -1, wall + 6])
                cube([4, wall + 2, back_d - 14]);

        // ---- tripod: 1/4-20 hex nut pocket + bolt clearance,
        // bottom wall under the screen bay
        translate([scr_x0 + scr_w/2, wall/2 + 0.6, 14])
            rotate([90, 0, 0]) {
                cylinder(d=6.8, h=wall+2, center=true);     // bolt
                translate([0, 0, -wall])
                    cylinder(d=11.4/cos(30), h=wall, $fn=6); // nut
            }
    }

    // Pi 5 bosses on the floor, bay centered behind the screen
    pi_x0 = scr_x0 + (scr_w - pi_w)/2;
    pi_y0 = face_cy - pi_h/2;
    for (p = [[pi_hole_off, pi_hole_off],
              [pi_hole_off + pi_hole_dx, pi_hole_off],
              [pi_hole_off, pi_hole_off + pi_hole_dy],
              [pi_hole_off + pi_hole_dx, pi_hole_off + pi_hole_dy]])
        translate([pi_x0 + p[0], pi_y0 + p[1], wall])
            boss(4, screw_d=2.0, od=6.5);
}
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

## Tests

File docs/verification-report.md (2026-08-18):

# Verification report

Generated 2026-07-02 by measuring the final `wigglecam.kicad_pcb` directly. Every value below is a measurement or a machine check, not an assertion.

| # | Area | Rule | Measured | Verdict | Source |
|---|---|---|---|---|---|
| 1 | QSPI | flash within 20 mm of the RP2040 | 12.8 mm center-to-center | **PASS** | RP2040 hardware design guide (RP-008279-DS); PCB Artists RP2040 layout notes |
| 2 | QSPI | CLK is the longest QSPI trace | CLK 8.3 mm vs data 7.8-19.9 mm; SS total 50.1 mm incl. its off-bus BOOTSEL-button leg | **DEVIATION** | PCB Artists RP2040 layout notes. **Accepted:** the far-side data wraps exceed CLK by 11.6 mm ≈ 70 ps, about 1.9% of the 133 MHz half-period; the rule targets much faster/longer buses. Data arrive early relative to CLK, which errs in the safe direction for setup time. |
| 3 | QSPI | data lines length-matched | spread 12.1 mm ≈ 73 ps | **PASS** | RP2040 datasheet timing budget (SDR, 7.5 ns period) |
| 4 | QSPI | trace width ~0.15 mm | widths [0.15] | **PASS** | PCB Artists RP2040 layout notes |
| 5 | QSPI | series R in SCLK near the flash | 27 Ω at 6.3 mm from flash | **PASS** | PCB Artists RP2040 layout notes (series termination option) |
| 6 | Crystal | load caps adjacent to the crystal | cap-to-crystal-pad 3.2, 5.7 mm | **PASS** | RP2040 hardware design guide §2.2 |
| 7 | Crystal | XIN/XOUT short | total crystal-net copper 44.6 mm (includes both load-cap ties and the series-R leg; the direct U2-to-crystal legs are the ~5 mm placement distance) | **DEVIATION** | RP2040 hardware design guide §2.2. **Accepted:** longer than a hand-optimized layout (the Pico achieves ~10 mm total) because the load-cap ties detour around the congested region. A 12 MHz fundamental crystal is highly tolerant of load-trace length; the ties run over the solid In1 GND plane. Flagged for visual review. |
| 8 | Crystal | crystal nets isolated from QSPI | min endpoint separation 6.9 mm | **PASS** | RP2040 hardware design guide §2.2 (keep XIN/XOUT away from fast signals) |
| 9 | Decoupling | 100 nF adjacent to every RP2040 power pin | pin-to-nearest-cap 2.5-8.0 mm (2 of 8 pins <3 mm) | **DEVIATION** | RP2040 hardware design guide §2.1 (place decoupling close). **Accepted:** most pins sit 3.8-8.0 mm from their nearest cap pad; the worst are IOVDD pins 33 (8.0 mm) and 22 (6.1 mm), whose natural spots the USB corridor and QSPI fanout own. Every measured pin reaches the 3V3 plane through a via within 3.3 mm (pin 22 at 1.3 mm, pin 33 at 1.9 mm), so decoupling works through the plane rather than pad-to-pad, which is worse than the guide's intent but tolerable at these edge rates. Flagged in the review checklist. |
| 10 | Decoupling | QFN center pad stitched to GND with >=9 vias | 9 vias in the EP | **PASS** | RP2040 hardware design guide §2.1 |
| 11 | USB | pair length-matched | DP 39.6 mm vs DM 40.4 mm (Δ 0.8 mm; USB-FS intra-pair budget is generous) | **PASS** | USB 2.0 spec §7.1.6 (FS); Intel HSD guidelines for FS routing |
| 12 | USB | differential geometry 0.36 mm width (90 Ω on JLC04161H-7628 per JLCPCB impedance calculator; the oft-cited 0.8 mm applies to 2-layer 1.6 mm boards) with documented 0.25/0.3 mm necks at the QFN and connector fields | widths used: [0.25, 0.3, 0.36] | **PASS** | JLCPCB impedance calculator (JLC04161H-7628); deviation documented below |
| 13 | USB | ESD array in the line before the MCU | USBLC6 carries CONN-side and ESD-side nets (flow-through) | **PASS** | ST USBLC6-2 datasheet, application diagram |
| 14 | Flash path | IPC-2221 width for 2 A at ΔT=10 °C on 1 oz: A=(I/(k·ΔT^0.44))^(1/0.725) = 42.4 mil² → 0.78 mm; VLED is a plane island (>=5 mm) and shares the 2 A across two 1 A branches | LED return widths [1.0] mm vs 1 A need 0.30 mm | **PASS** | IPC-2221A §6.2, external-layer chart |
| 15 | Flash path | highest-current distribution as pour, not trace | VLED In2 island area 684 mm² | **PASS** | IPC-2221A; standard practice for pulse rails |
| 16 | Power integrity | solid GND plane on In1 | 3455 mm² of 3800 mm² board | **PASS** | standard 4-layer practice; Ott, Electromagnetic Compatibility Engineering ch.16 |
| 17 | Power integrity | no signal routing through the planes (no plane splits under high-speed nets) | 0 track segments on In1/In2 | **PASS** | Ott ch.16; verified by layer scan |
| 18 | Power integrity | reservoir sizing: 2×470 µF polymer supplies the 2 A pulse front; steady-state comes from the X1202 5 V rail (5 A). ΔV = I·t/C for the first 1 ms before the rail responds: 2 A × 1 ms / 940 µF ≈ 2.1 V worst-case droop locally, recovered by the rail; low-ESR polymer chosen for this reason | 2×470 µF EIA-7343 polymer on VLED at the reservoir pocket | **PASS** | standard reservoir sizing; part choice documented in BOM |
| 19 | Power integrity | input protection chain present | PI5V → PTC 3 A → AO3401A reverse-polarity P-FET → VLED | **PASS** | netlist topology check; AOS AO3401A datasheet |
| 20 | DFM | DRC clean at JLCPCB 4-layer capability limits (min track 0.127, clearance 0.127, via 0.4/0.25, annular 0.1, edge 0.3, hole-to-copper 0.254) | 0 violations, 0 unconnected | **PASS** | kicad-cli drc --refill-zones (report committed); jlcpcb.com/capabilities 4-layer |
| 21 | DFM | min track width used >= 0.127 mm | 0.150 mm | **PASS** | JLCPCB capabilities |
| 22 | DFM | min via >= 0.4/0.2 mm (JLC min 0.25 hole for 4-layer mechanical; ours 0.25 drill / 0.5 dia) | smallest via (0.5, 0.25) (dia, drill) of 188 vias | **PASS** | JLCPCB capabilities |
| 23 | Assembly | hand-solderable: no BGA; finest pitch is the RP2040 QFN-56 at 0.4 mm (hard but standard with flux + drag-soldering or hot air; everything else is 0603+/SOIC/SOT) | packages: 27 kinds; finest: ['QFN-56-1EP_7x7mm_P0.4mm_EP3.2x3.2mm'] | **PASS** | design constraint from the brief |
| 24 | Assembly | fiducials for pick-and-place | 3 fiducials (FID1-3) | **PASS** | JLCPCB SMT guidelines |

## Known deviations & NEEDS-REVIEW items

These are called out rather than hidden:

- **USB differential width** deviates from the commonly quoted 0.8 mm because that figure assumes a 2-layer 1.6 mm board; on JLC04161H-7628 the 90 Ω geometry is ≈0.36 mm (JLCPCB impedance calculator). Short 0.25/0.3 mm necks exist at the QFN pads and connector field; at USB-FS (12 Mbps) these are electrically negligible.
- **USB series resistors** sit mid-corridor (~15 mm from the RP2040) rather than hard against it, a placement-congestion trade-off that is acceptable at FS speeds.
- **A handful of via-in-pad plane taps** were used where the fanout was too dense for offset stubs (flagged for review). For hand assembly this is a non-issue; for reflow, request unfilled vias or accept minor solder wicking on those 0603 pads.
- **The last few link closures** were validated only by the DRC gate; give the affected areas (encoder net ENC_A's cross-board route, the VLED island patches) a visual pass in the KiCad GUI before ordering.
- **VREG_1V1 pin-23 leg** routes via B.Cu under the crystal pocket; verify visually that it keeps clear of the XIN/XOUT region (DRC passes; the concern is aesthetic/EMI-marginal).

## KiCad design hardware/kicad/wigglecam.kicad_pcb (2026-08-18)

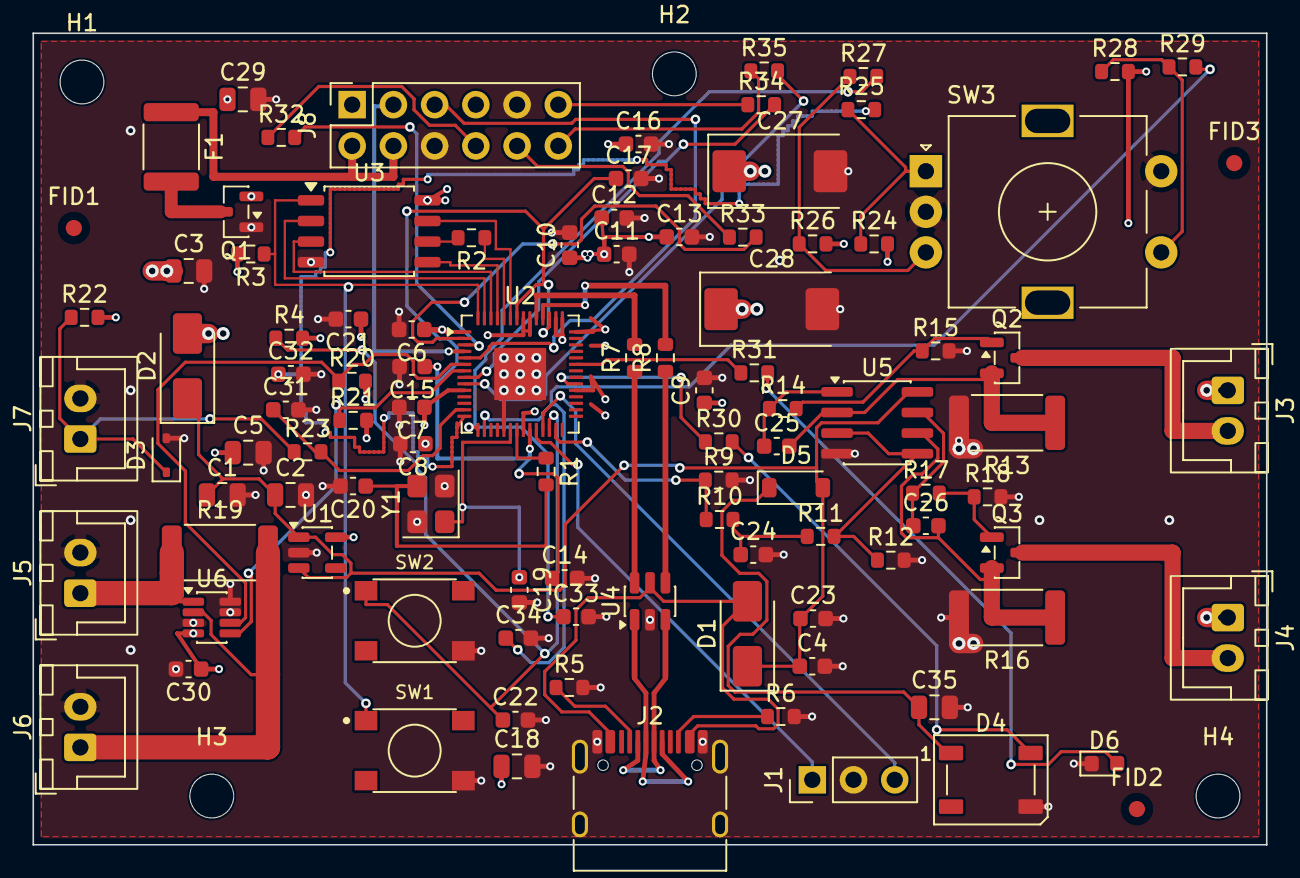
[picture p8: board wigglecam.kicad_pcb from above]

Board: 4 copper layers, 76.0 x 50.0 mm, 105 parts (0 on the bottom side), 67 nets.

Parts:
C1, C2: 22uF; C_0805_2012Metric
C3, C5, C18, C29, C35: 10uF; C_0805_2012Metric
C4, C16, C17, C24: 1uF; C_0603_1608Metric
C6, C7, C8, C9, C10, C11, C12, C13, C14, C15, C21, C22, C23, C30, C31, C32, C33, C34: 100nF; C_0603_1608Metric
C19, C20: 15pF; C_0603_1608Metric
C25, C26: 1nF; C_0603_1608Metric
C27, C28: 470uF; CP_EIA-7343-30_AVX-N
D1, D2: SS34; D_SMA
D3: PESD5V0S1BA; D_SOD-323
D4: WS2812B; LED_WS2812B_PLCC4_5.0x5.0mm_P3.2mm
D5: 1N4148W; D_SOD-123
D6: GREEN; LED_0603_1608Metric
F1: PTC 3A; Fuse_1812_4532Metric
FID1, FID2, FID3: Fiducial_1mm_Mask2mm
H1, H2, H3, H4: MountingHole_2.7mm_M2.5
J1: SWD; PinHeader_1x03_P2.54mm_Vertical
J2: USB-C; USB_C_Receptacle_HRO_TYPE-C-31-M-12
J3: LED1; JST_XH_B2B-XH-A_1x02_P2.50mm_Vertical
J4: LED2; JST_XH_B2B-XH-A_1x02_P2.50mm_Vertical
J5: VBAT_IN; JST_XH_B2B-XH-A_1x02_P2.50mm_Vertical
J6: VBAT_OUT; JST_XH_B2B-XH-A_1x02_P2.50mm_Vertical
J7: SHUTTER; JST_XH_B2B-XH-A_1x02_P2.50mm_Vertical
J8: Pi GPIO 1-12; PinSocket_2x06_P2.54mm_Vertical
Q1: AO3401A; SOT-23
Q2, Q3: AO3400A; SOT-23
R1, R10, R23, R25, R27, R29, R31: 1k; R_0603_1608Metric
R2, R7, R8: 27R; R_0603_1608Metric
R3, R4, R22, R24, R26, R28: 10k; R_0603_1608Metric
R5, R6: 5.1k; R_0603_1608Metric
R9, R15, R18: 100k; R_0603_1608Metric
R11: 5.6k; R_0603_1608Metric
R12: 1.2k; R_0603_1608Metric
R13, R16: 0.5R 1%; R_2512_6332Metric
R14, R17: 100R; R_0603_1608Metric
R19: 10mR 2W 1%; R_2512_6332Metric
R20, R21: 4.7k; R_0603_1608Metric
R30: 470R; R_0603_1608Metric
R32, R33, R34, R35: 330R; R_0603_1608Metric
SW1, SW2: TACT; SW_TS-1187A_5.1x5.1mm
SW3: EC11; RotaryEncoder_Alps_EC11E-Switch_Vertical_H20mm
U1: AP2112K-3.3; SOT-23-5
U2: RP2040; QFN-56-1EP_7x7mm_P0.4mm_EP3.2x3.2mm
U3: W25Q128JVSIQ; SOIC-8_5.3x5.3mm_P1.27mm
U4: USBLC6-2SC6; SOT-23-6
U5: LM358; SOIC-8_3.9x4.9mm_P1.27mm
U6: INA219; SOT-23-8
Y1: 12MHz; Crystal_SMD_3225-4Pin_3.2x2.5mm

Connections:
+3V3: C5.1, C6.1, C7.1, C8.1, C9.1, C10.1, C11.1, C12.1, C13.1, C16.1, C18.1, C21.1, C30.1, R3.2, R4.2, R20.2, R21.2, R22.2, R24.2, R26.2, R28.2, U1.5, U2.1, U2.10, U2.22, U2.33, U2.42, U2.43, U2.44, U2.48, U2.49, U3.8, U6.4
CAM_SYNC: R34.2, U2.8
CAM_SYNC_HDR: J8.11, R34.1
ENC_A: C32.1, R25.2, U2.14
ENC_A_RAW: R24.1, R25.1, SW3.A
ENC_B: C33.1, R27.2, U2.15
ENC_B_RAW: R26.1, R27.1, SW3.B
ENC_SW1: C34.1, R29.2, U2.16
ENC_SW1_RAW: R28.1, R29.1, SW3.S1
FLASH_PWM: R9.1, R10.1, U2.27
GND: C1.2, C2.2, C3.2, C4.2, C5.2, C6.2, C7.2, C8.2, C9.2, C10.2, C11.2, C12.2, C13.2, C14.2, C15.2, C16.2, C17.2, C18.2, C19.2, C20.2, C21.2, C22.2, C23.2, C24.2, C27.2, C28.2, C29.2, C30.2, C31.2, C32.2, C33.2, C34.2, C35.2, D3.2, D4.3, D6.1, J1.2, J2.A1, J2.A12, J2.B1, J2.B12, J2.SH, J5.2, J6.2, J7.2, J8.6, J8.9, Q1.1, R5.2, R6.2, R9.2, R12.2, R13.2, R15.2, R16.2, R18.2, SW1.4, SW2.4, SW3.C, SW3.S2, U1.2, U2.19, U2.57, U3.4, U4.2, U5.4, U6.3, U6.7, U6.8, Y1.2, Y1.4
I2C0_SCL: R21.1, U2.7, U6.5
I2C0_SDA: R20.1, U2.6, U6.6
unnamed: J1.1, U2.24
unnamed: J1.3, U2.25
unnamed: J2.A5, R5.1
unnamed: J2.B5, R6.1
unnamed: C25.1, R14.1, U5.1
unnamed: Q2.1, R14.2, R15.1
unnamed: J3.2, Q2.3
unnamed: C26.1, R17.1, U5.7
unnamed: Q3.1, R17.2, R18.1
unnamed: J4.2, Q3.3
unnamed: R31.1, U2.37
unnamed: D6.2, R31.2
PI5V_FUSED: F1.2, Q1.3
PI5V_RAW: F1.1, J8.2, J8.4
PI_SCL: J8.5, U2.5
PI_SDA: J8.3, U2.4
QSPI_SCLK: R2.1, U2.52
QSPI_SCLK_FL: R2.2, U3.6
QSPI_SD0: U2.53, U3.5
QSPI_SD1: U2.55, U3.2
QSPI_SD2: U2.54, U3.3
QSPI_SD3: U2.51, U3.7
QSPI_SS: R3.1, SW1.1, U2.56, U3.1
RUN: C22.1, R4.1, SW2.1, U2.26
SENSE1: C25.2, Q2.2, R13.1, U5.2
SENSE2: C26.2, Q3.2, R16.1, U5.6
SHUTTER_N: C31.1, R23.2, U2.13
SHUTTER_RAW: D3.1, J7.1, R22.1, R23.1
SPARE_IO: R35.2, U2.9
SPARE_IO_HDR: J8.12, R35.1
UART_RX: R32.2, U2.3
UART_RX_HDR: J8.8, R32.1
UART_TX: R33.2, U2.2
UART_TX_HDR: J8.10, R33.1
USB_DM: R8.2, U2.46
USB_DM_CONN: J2.A7, J2.B7, U4.3
USB_DM_ESD: R8.1, U4.4
USB_DP: R7.2, U2.47
USB_DP_CONN: J2.A6, J2.B6, U4.1
USB_DP_ESD: R7.1, U4.6
VBAT_IN: J5.1, R19.1, U6.1
VBAT_OUT: J6.1, R19.2, U6.2
VBUS: D1.2, J2.A4, J2.A9, J2.B4, J2.B9, U4.5
VLED: C3.1, C27.1, C28.1, C29.1, D2.2, J3.1, J4.1, Q1.2
VREF: R11.2, R12.1, U5.3, U5.5
VREF_RAW: C24.1, R10.2, R11.1
VREG_1V1: C14.1, C15.1, C17.1, U2.23, U2.45, U2.50
VSYS: C1.1, C2.1, C4.1, C23.1, D1.1, D2.1, D5.2, U1.1, U1.3, U5.8
WS_DIN: R30.1, U2.34
WS_DIN_R: D4.4, R30.2
WS_VDD: C35.1, D4.1, D5.1
XIN: C19.1, U2.20, Y1.1
XOUT: R1.1, U2.21
XOUT_XTAL: C20.1, R1.2, Y1.3

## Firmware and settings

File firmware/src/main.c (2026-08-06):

// WiggleCam Camera Controller firmware.
//
// Role: real-time/analog sidecar for the Raspberry Pi 5. The Pi is
// I2C master (we are a 16-register slave at 0x17); this core handles
// flash current control with hard safety limits, shutter debounce,
// EC11 quadrature, battery telemetry via INA219, the WS2812 status
// LED, and the camera-sync pulse.

#include "pico/stdlib.h"
#include "hardware/watchdog.h"
#include "hardware/i2c.h"
#include "hardware/irq.h"
#include "hardware/sync.h"

#include "board.h"
#include "registers.h"
#include "i2c_slave.h"
#include "ina219.h"
#include "encoder.h"
#include "flash_led.h"
#include "ws2812.h"

static uint8_t regs[REG_COUNT];

// Pending capture/flash request. The I2C slave IRQ only records it;
// the main loop dispatches, so no blocking work ever runs in the ISR.
enum { REQ_NONE = 0, REQ_SYNC = 1, REQ_FLASH_SYNC = 2, REQ_FLASH_ONLY = 3 };
static volatile uint8_t flash_req;

// VBAT/IBAT high bytes latched when the low byte is read, so a 16-bit
// read can't tear against the 250 ms telemetry refresh.
static uint8_t vbat_h_latch, ibat_h_latch;

// ---------------------------------------------------------------- events --
static volatile uint8_t button_events;
static volatile uint32_t shutter_last_ms;

static void update_attn(void) {
    gpio_put(PIN_ATTN, button_events != 0 || encoder_pending());
}

static void shutter_irq(uint gpio, uint32_t events) {
    (void)events;
    uint32_t now = to_ms_since_boot(get_absolute_time());
    if (gpio == PIN_SHUTTER) {
        if (now - shutter_last_ms > 30) {   // debounce (RC did stage 1)
            button_events |= 1u << 0;
            shutter_last_ms = now;
        }
    } else if (gpio == PIN_ENC_SW) {
        button_events |= 1u << 1;
    } else {
        encoder_irq(gpio);
    }
    update_attn();
}

// ------------------------------------------------------------- I2C hooks --
// Called from the slave IRQ: master reads register `addr`.
static uint8_t on_read(uint8_t addr) {
    switch (addr) {
    case REG_WHO_AM_I:  return WHO_AM_I_VALUE;
    case REG_STATUS:
        return (flash_busy() ? STATUS_FLASH_BUSY : 0) |
               ((button_events || encoder_pending()) ? STATUS_EVENT : 0);
    case REG_ENC_DELTA: {
        int8_t d = encoder_take_delta();
        update_attn();
        return (uint8_t)d;
    }
    case REG_VBAT_L:
        vbat_h_latch = regs[REG_VBAT_H];   // pair snapshot, see above
        return regs[REG_VBAT_L];
    case REG_VBAT_H:
        return vbat_h_latch;
    case REG_IBAT_L:
        ibat_h_latch = regs[REG_IBAT_H];
        return regs[REG_IBAT_L];
    case REG_IBAT_H:
        return ibat_h_latch;
    case REG_BUTTONS: {
        uint8_t b = button_events;
        button_events = 0;
        update_attn();
        return b;
    }
    default:
        return addr < REG_COUNT ? regs[addr] : 0xFF;
    }
}

static void on_write(uint8_t addr, uint8_t value) {
    switch (addr) {
    case REG_TRIGGER:
        // only the documented values act; anything else is ignored
        if (value == REQ_SYNC || value == REQ_FLASH_SYNC)
            flash_req = value;         // main loop dispatches
        break;
    case REG_FIRE_FLASH:
        flash_req = REQ_FLASH_ONLY;
        break;
    case REG_FLASH_MS:
        regs[addr] = value > FLASH_MAX_MS ? FLASH_MAX_MS
                     : (value == 0 ? 1 : value);
        break;
    case REG_FLASH_PCT:
        regs[addr] = value > 100 ? 100 : value;
        break;
    case REG_LED_APPLY:
        ws2812_set(regs[REG_LED_R], regs[REG_LED_G], regs[REG_LED_B]);
        break;
    case REG_LED_R:
    case REG_LED_G:
    case REG_LED_B:
        regs[addr] = value;
        break;
    default:
        break;    // read-only or unmapped: drop the write
    }
}

int main(void) {
    // status/attention outputs first: defined levels ASAP after boot
    gpio_init(PIN_ATTN);
    gpio_set_dir(PIN_ATTN, GPIO_OUT);
    gpio_put(PIN_ATTN, 0);
    gpio_init(PIN_DEBUG_LED);
    gpio_set_dir(PIN_DEBUG_LED, GPIO_OUT);

    flash_init();          // claims PIN_FLASH_PWM, holds reference at 0
    ws2812_init(PIN_WS2812);
    encoder_init(PIN_ENC_A, PIN_ENC_B);

    // inputs
    for (uint pin = 0; pin < 2; pin++) {
        uint p = pin == 0 ? PIN_SHUTTER : PIN_ENC_SW;
        gpio_init(p);
        gpio_set_dir(p, GPIO_IN);
        gpio_pull_up(p);   // belt-and-braces; board has 10k pullups
        gpio_set_irq_enabled(p, GPIO_IRQ_EDGE_FALL, true);
    }
    gpio_set_irq_enabled(PIN_ENC_A, GPIO_IRQ_EDGE_RISE | GPIO_IRQ_EDGE_FALL,
                         true);
    gpio_set_irq_enabled(PIN_ENC_B, GPIO_IRQ_EDGE_RISE | GPIO_IRQ_EDGE_FALL,
                         true);
    gpio_set_irq_callback(&shutter_irq);
    irq_set_enabled(IO_IRQ_BANK0, true);

    // internal I2C master -> INA219
    i2c_init(i2c0, 400 * 1000);
    gpio_set_function(PIN_I2C_INT_SDA, GPIO_FUNC_I2C);
    gpio_set_function(PIN_I2C_INT_SCL, GPIO_FUNC_I2C);
    ina219_init(i2c0, INA219_ADDR);

    // Pi-facing I2C slave
    regs[REG_FLASH_MS] = 30;
    regs[REG_FLASH_PCT] = 80;
    i2c_slave_setup(i2c1, PIN_I2C_SLAVE_SDA, PIN_I2C_SLAVE_SCL,
                    I2C_SLAVE_ADDR, on_read, on_write);

    // Matched to FLASH_MAX_MS: the LEDs are switched off in flash_poll(),
    // so a stalled main loop leaves them lit until the watchdog resets and
    // the 100k pulldown pulls the sink reference to 0. Setting the timeout
    // to the pulse budget means even that fault path can't exceed the
    // thermal case the sinks are dispositioned for. Worst-case normal
    // iteration is ~10 ms (two INA219 transfers, 2 ms timeout each), so
    // this still leaves >10x margin.
    watchdog_enable(FLASH_MAX_MS, true);

    uint32_t last_batt = 0, last_blink = 0;
    while (true) {
        watchdog_update();
        flash_poll();      // walks the flash/sync state machine
        uint32_t save_irq = save_and_disable_interrupts();
        uint8_t req = flash_req;   // take-and-clear atomically, so a
        flash_req = REQ_NONE;      // request landing mid-check isn't lost
        restore_interrupts(save_irq);
        if (req != REQ_NONE) {
            switch (req) {
            case REQ_SYNC:
                flash_sync_pulse_only();
                break;
            case REQ_FLASH_SYNC:
                // no flash configured, or refused (cooldown): still give
                // the Pi its sync edge so its capture loop never hangs
                if (regs[REG_FLASH_PCT] == 0 ||
                    !flash_fire(regs[REG_FLASH_MS], regs[REG_FLASH_PCT],
                                true))
                    flash_sync_pulse_only();
                break;
            case REQ_FLASH_ONLY:
                (void)flash_fire(regs[REG_FLASH_MS], regs[REG_FLASH_PCT],
                                 false);
                break;
            }
        }
        uint32_t now = to_ms_since_boot(get_absolute_time());
        if (now - last_batt >= 250) {
            last_batt = now;
            int mv = ina219_bus_mv();
            int ma = ina219_current_ma();
            if (mv >= 0) {           // on error keep the last good sample
                // all four bytes land atomically w.r.t. the I2C IRQ;
                // with the low-byte latch above, a 16-bit read always
                // sees one coherent sample
                uint32_t save = save_and_disable_interrupts();
                regs[REG_VBAT_L] = mv & 0xFF;
                regs[REG_VBAT_H] = (mv >> 8) & 0xFF;
                regs[REG_IBAT_L] = ma & 0xFF;
                regs[REG_IBAT_H] = (ma >> 8) & 0xFF;
                restore_interrupts(save);
            }
        }
        if (now - last_blink >= 500) {
            last_blink = now;
            gpio_xor_mask(1u << PIN_DEBUG_LED);   // heartbeat
        }
        tight_loop_contents();
    }
}

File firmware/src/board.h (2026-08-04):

// Pin map. Must match hardware/skidl/circuit.py exactly.
#pragma once

#define PIN_UART_TX      0   // -> Pi RXD (GPIO15)
#define PIN_UART_RX      1   // <- Pi TXD (GPIO14)
#define PIN_I2C_SLAVE_SDA 2  // Pi I2C1 (Pi GPIO2)
#define PIN_I2C_SLAVE_SCL 3  // Pi I2C1 (Pi GPIO3)
#define PIN_I2C_INT_SDA  4   // internal bus: INA219
#define PIN_I2C_INT_SCL  5
#define PIN_CAM_SYNC     6   // -> Pi GPIO17, capture-sync pulse
#define PIN_ATTN         7   // -> Pi GPIO18, "event pending" flag
#define PIN_SHUTTER      10  // active low, RC-conditioned
#define PIN_ENC_A        11
#define PIN_ENC_B        12
#define PIN_ENC_SW       13  // active low
#define PIN_FLASH_PWM    16  // filtered PWM -> current-sink reference
#define PIN_WS2812       22
#define PIN_DEBUG_LED    25

#define I2C_SLAVE_ADDR   0x17
#define INA219_ADDR      0x40

// Flash safety limits (mirror the hardware: 100k pulldown keeps the
// reference at 0 V until firmware drives it)
#define FLASH_MAX_MS     150
#define FLASH_COOLDOWN_MS 800

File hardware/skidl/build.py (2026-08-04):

"""Build the Camera Controller netlist: ERC + KiCad netlist + JSON bridge.

Run:  python3 build.py
Outputs (in hardware/):
  netlist.net   KiCad-format netlist (committed deliverable)
  board.json    {parts: [{ref, name, value, footprint, lcsc,
                   pads: {padnum: netname}}], nets: [...]}
                  consumed by the pcbnew layout scripts, so the
                  layout stage has zero dependence on netlist parsing.
"""

import json
import sys
from pathlib import Path

sys.path.insert(0, str(Path(__file__).parent))

from skidl import ERC, generate_netlist

import circuit as ckt
from builtins import default_circuit  # injected by skidl on import

HW = Path(__file__).resolve().parent.parent


def main():
    ckt.power_input()
    ckt.regulator_3v3()
    u = ckt.mcu_core()
    ckt.usb(u)
    ckt.flash_driver(u)
    ckt.battery_monitor(u)
    ckt.controls(u)
    ckt.pi_header(u)

    ERC()
    generate_netlist(file_=str(HW / "netlist.net"))

    parts = []
    for part in default_circuit.parts:
        pads = {}
        for pin in part.pins:
            if (pin.net is not None and pin.net.name != "NC"
                    and not pin.net.name.startswith("__NOCONNECT")):
                pads[str(pin.num)] = pin.net.name
        parts.append({
            "ref": part.ref,
            "name": part.name,
            "value": str(part.value),
            "footprint": part.footprint,
            "lcsc": part.fields.get("LCSC", ""),
            "pads": pads,
        })
    nets = sorted({n.name for n in default_circuit.nets
                   if n.name not in ("NC",)})
    (HW / "board.json").write_text(
        json.dumps({"parts": parts, "nets": nets}, indent=1))
    print(f"parts={len(parts)} nets={len(nets)}")
    print("WROTE", HW / "netlist.net", HW / "board.json")


if __name__ == "__main__":
    main()

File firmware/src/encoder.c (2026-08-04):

// EC11 quadrature decode, IRQ-driven with a full state-transition
// table (rejects invalid transitions = contact bounce immunity).
// EC11E18244AU: 36 detents/18 pulses per rev, one detent every half
// quadrature cycle = 2 valid transitions per detent with this table;
// divide accordingly.

#include "pico/stdlib.h"
#include "hardware/sync.h"
#include "encoder.h"
#include "board.h"

static volatile int32_t count;
static volatile uint8_t prev_state;

// index: (prev<<2)|curr; value: -1, 0, +1
static const int8_t TRANSITION[16] = {
     0, -1, +1,  0,
    +1,  0,  0, -1,
    -1,  0,  0, +1,
     0, +1, -1,  0,
};

void encoder_init(uint pin_a, uint pin_b) {
    gpio_init(pin_a); gpio_set_dir(pin_a, GPIO_IN); gpio_pull_up(pin_a);
    gpio_init(pin_b); gpio_set_dir(pin_b, GPIO_IN); gpio_pull_up(pin_b);
    prev_state = (gpio_get(PIN_ENC_A) << 1) | gpio_get(PIN_ENC_B);
}

void encoder_irq(uint gpio) {
    (void)gpio;
    uint8_t curr = (gpio_get(PIN_ENC_A) << 1) | gpio_get(PIN_ENC_B);
    count += TRANSITION[(prev_state << 2) | curr];
    prev_state = curr;
}

int8_t encoder_take_delta(void) {
    uint32_t save = save_and_disable_interrupts();
    int32_t c = count;
    int32_t detents = c / 2;      // 2 valid edges per detent
    if (detents > 127) detents = 127;
    if (detents < -128) detents = -128;
    count = c - detents * 2;      // keep the sub-detent remainder, so a
                                  // detent straddling two polls is
                                  // reported on the next read, not lost
    restore_interrupts(save);
    return (int8_t)detents;
}

bool encoder_pending(void) {
    int32_t c = count;
    return c >= 2 || c <= -2;     // at least one full detent latched
}

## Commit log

2026-07-02 Scaffold: execution plan and LCSC stock-verified part list
    Repository structure for the RP2040 camera-controller board.
    docs/plan.md lays out the phased automated design flow (SKiDL netlist,
    scripted placement, constrained routing + Freerouting, DRC gate, JLCPCB
    fab outputs, Pico SDK firmware, programmatic layout verification).
    hardware/partlist.md carries the part list with every named component
    verified in LCSC stock as of 2026-07-02, including the flash-driver
    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
2026-07-02 Schematic as code: full connectivity, ERC clean, netlist + layout bridge
    98 parts, 68 nets across seven blocks (power input with reverse-polarity
    P-FET and diode-OR, AP2112K 3.3V rail, RP2040 core per the official
    hardware design guide, USB-C with flow-through ESD, two-branch op-amp
    constant-current flash sink, INA219 battery pass-through monitor,
    controls and Pi header). Every part carries an explicit datasheet pin
    map and stock-verified LCSC number. SKiDL ERC: 0 errors, 0 warnings.
    board.json carries pad->net binding for the layout stage.
    [build.py, build_sklib.py, circuit.py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]
2026-07-02 Board: 76x50 4-layer, scripted placement + critical-net pre-routes, DRC clean
    98 parts placed by anchor table + net-signature-driven auto-placer
    (decoupling adjacency computed from real pad coordinates, corridor
    reservations for sensitive routes, collision-aware VLED stubs).
    Critical nets routed by script and verified to zero DRC errors:
    QSPI nested-lane fanout with inline SCLK series R, crystal, USB
    differential pair (mirror-pad jumpers via B.Cu taps, one controlled
    B.Cu crossover), power entry, LED return paths, In1 GND plane, In2
    3V3 + VLED island. 201 low-speed connections remain for the
    autorouter. Also: firmware source (Pico SDK) and layout tooling.
    [wigglecam.kicad_pcb]
2026-07-02 Firmware: I2C-slave command set, flash safety limits, peripherals; builds clean
    Pico SDK C application: register-file I2C slave (0x17) for the Pi,
    constant-current flash control with 150 ms cap + 800 ms cooldown +
    watchdog, INA219 battery telemetry, EC11 quadrature decode with a
    transition-table debounce, shutter events with an ATTN line to the Pi,
    WS2812B status LED via PIO. camctrl.uf2 builds with the Pico SDK and
    xpack arm-none-eabi GCC 14.2.
    [wigglecam.dsn]
2026-07-02 Board fully routed, DRC clean: 0 errors, 0 unconnected (JLCPCB 4-layer rules)
    Hybrid flow as planned: scripted critical nets (QSPI nested lanes,
    crystal, USB differential pair with mirror-pad B.Cu jumpers, power
    entry, battery path, LED returns, plane fanout stubs and QFN interior
    power fanouts), Freerouting 1.9 for the low-speed remainder (inner
    plane layers marked unroutable, completed nets stripped from the DSN,
    outline shrunk for edge clearance), zone pours with island removal,
    then scripted finishing passes closing the final airwires with
    collision-checked geometry (05_finish through 05i, incl. a dual-layer
    BFS maze route for the ENC_A leg). The full DRC gate runs kicad-cli
    with refille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
    [wigglecam.dsn, wigglecam.kicad_pcb]
2026-07-02 Fab outputs, verification report, rationale, review checklist, final README
    Gerbers/drill/BOM/CPL in JLCPCB format with board renders. The
    verification report measures the finished layout programmatically:
    24 checks against the RP2040 hardware design guide, IPC-2221,
    USB-FS routing guidance and JLCPCB capabilities — no failures;
    measured deviations (QSPI wrap lengths vs CLK, crystal tie length,
    two displaced decouplers, USB width vs the 2-layer rule of thumb)
    are analyzed and dispositioned rather than hidden. The human review
    checklist separates hand-constrained regions from autorouted ones
    and lists every NEEDS-REVIEW item.
    [bom.csv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]
2026-07-02 Enclosure: PCB-driven control pod (screen + controller + Pi 5)
    Two-shell OpenSCAD case whose board-facing features (mounting bosses,
    encoder bushing hole, light pipe, button poke-holes, USB-C window,
    JST cable slots) are generated from the routed .kicad_pcb by an
    extraction script, so the case cannot drift from the PCB. The board
    mounts rotated 90° CCW behind the face, components outward — the
    transform was derived and checked to be a rigid rotation (no mirror).
    STLs exported and verified manifold; renders committed; ordering and
    assembly guide included.
    [board_dims.scad, control_pod.scad, pod_back.stl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]
2026-07-03 BOM: verified LCSC numbers for every SMT line; order-readiness audit
    - Generic R/C lines get concrete LCSC picks (each number verified
    against its LCSC product page for value + package, 2026-07-03);
    resistors are JLC-basic UNI-ROYAL 0603WAF parts.
    - USB series Rs changed 27.4R -> 27R (guide-nominal; equivalent at
    USB-FS) so R2/R7/R8 share the basic part C25190. Board Value
    fields, netlist, BOM and CPL regenerated; positions/rotations
    byte-identical, ERC and DRC re-run clean (0/0).
    - 470 uF reservoir resolved to Panasonic 6TPE470MI POSCAP (C402828,
    18 mOhm) per the checklist's ESR requirement.
    - JST shells pinned to genuine B2B-XH-A (C158012); SWD header and
    2x6 Pi socket left u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
    [bom.csv, wigglecam.kicad_pcb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]
2026-07-18 README: tighten to a presentation overview
    Lead with what the board is and does. Move the ordering/bring-up
    sequence and the pre-order review checklist out of the repo into
    local working notes.
2026-07-18 README: cut to essentials
2026-07-29 Firmware: no blocking work in the I2C ISR; telemetry and encoder fixes
    - TRIGGER handling was calling sleep_ms() from the slave IRQ; on
    M0+ the timer IRQ can't preempt at the same priority, so the wait
    never returned and the watchdog fired with the flash sinks still
    at full current. Register writes now just post a request; the main
    loop dispatches, and flash_fire()/sync run as a nonblocking state
    machine in flash_poll(). Settle time now counts against the 150 ms
    cap; unknown TRIGGER values are ignored; STATUS gates re-triggering.
    - I2C RX parser keys off the hardware FIRST_DATA_BYTE flag instead of
    a byte-counting heuristic, so back-to-back transactions can't
    desync the regis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
    [bom.csv]
2026-07-31 Trigger semantics: sync edge always arrives; R12 value propagated
    - STATUS bit0 now covers any trigger-engine activity (flash or sync
    pulse), and a TRIGGER=2 refused by the 800 ms cooldown degrades to a
    sync-only pulse instead of vanishing - the Pi's capture loop can no
    longer hang waiting for an edge that never comes. flash_fire()
    reports refusal so the dispatcher can fall back.
    - ws2812 writes drop on a full FIFO instead of blocking (reachable
    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
    [bom.csv, wigglecam.kicad_pcb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]
2026-08-03 README: rewrite in plainer language, fix a few overclaims
    Rewrote the front page so it reads the way I'd actually explain the
    project. Also corrected some things the old wording got wrong or
    oversold: the board isn't fabricated, DRC clean against JLCPCB's
    published rules is my own check and not a manufacturer's, and the
    capture pulse rides a dedicated GPIO line rather than I2C.
2026-08-04 Docs: plainer wording throughout
    Rewrote the README in a plainer register and swept the rest of the
    repo for the same: replaced dashes used as punctuation, dropped the
    stock phrasings, and cut a few lines that read like product copy.
    Only comments and docstrings changed in source files. No technical
    content, numbers, or claims were altered.
    [board.h, build.py, circuit.py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]
2026-08-06 Watchdog matched to the flash pulse budget
    The sinks are switched off in flash_poll(), so a stalled main loop
    leaves the LEDs lit until the watchdog resets and the 100k pulldown
    takes the reference to 0. At 500 ms that fault path allowed 3.3x the
    150 ms pulse the SOT-23 sinks are dispositioned for. Worst-case normal
    iteration is ~10 ms (two INA219 transfers at a 2 ms timeout each), so
    matching the timeout to FLASH_MAX_MS keeps >10x margin while bounding
    the fault case to the thermal budget.
    Also include hardware/irq.h explicitly instead of relying on it
    arriving through pico/stdlib.h.
    [main.c]
2026-08-08 Docs: drop routing-process narration
    Describe the layout constraints and what they buy, not the mechanics of
    how the traces were placed.
2026-08-18 Move internal tooling out of the published tree
    The generation and verification scripts, the KiCad intermediates and
    the tool logs are working files, not part of the design record. They
    move to private/ (gitignored) alongside the working notes. The design
    outputs stay: schematic source, board, fab package, firmware, docs.
    [board_dims.scad, wigglecam.dsn]
2026-08-18 Untrack private/ so the ignore rule applies
    git mv kept them staged; removing from the index leaves the files on
    disk and out of the published tree.
    [wigglecam.dsn]
2026-08-18 R12 to 1.2 k, and split the JLC upload set from the hand-solder parts
    The E96 1.18 k is the exact fit for the flash reference divider but is
    thinly stocked. 1.2 k settles at 0.508 V instead of 0.5005 V, so
    1.015 A per branch instead of 1.001 A. The sense resistor sees 0.515 W
    against a 1 W part for at most 150 ms and the sinks are unchanged, so
    the 1.5 % costs nothing and the part is a common value. Changed in the
    schematic source, netlist, board, BOM, CPL and the docs that quote the
    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
    [bom-handsolder.csv, bom-smt.csv, bom.csv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]
2026-08-18 Document the U1 alternate
    ME6211C33M5G-N (C82942) is a same-pinout SOT-23-5 drop-in for the
    AP2112K and is deeply stocked. 500 mA against this board's 221 mA
    worst case, and 260 mV dropout against about a volt of headroom from
    VSYS, so the swap costs nothing.
2026-08-18 Record C22765 for R12
    The 1.2 k landed on a JLC basic part, so the one BOM line that had no
    number now has one. Also noted in the upload README that JLC's
    assembly inventory is a separate pool from LCSC retail, which is why
    a part can be buyable and still short in the BOM tool.
    [bom-smt.csv, bom.csv]
